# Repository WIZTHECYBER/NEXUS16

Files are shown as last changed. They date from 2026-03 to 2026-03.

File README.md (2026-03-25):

### **Nexus16: The Art of Control.**




>A 17-year-old and a 16-year-old, ordinary people in this world just trying to learn the ways of the world and finding our interests. Well, we found our way through Hack Club.
>They became the platform for us to start our skill development from the start and provided us with a challenging yet sufficient project to physically work on.
>A lot of the DIY projects are mostly individual hardware soldered together to form a working but fragile piece of machinery, but to us that was not going to cut it. So we decided to use professional approaches and slowly but surely we were making progress, and finally, now our hard work has paid off.

### **Meet the Nexus16:**
>Designed from the ground up to give you pure, uninterrupted control over your work, built to make you a professional and to provide you with a satisfactory experience.

### **The Engineering behind the PCB:**
>We made sure to input the details of Nexus16 in such a sophisticated manner that it is easy for everyone to learn, self-develop, and improvise it.

### **Casing:**
>We did not settle for an exquisite and overly-engineered design but rather chose to make the casing simple enough to 3D print for even low-tier 3D printers. Well, after spending a few grueling hours understanding and learning AutoCAD, we fabricated a design that looked simple and sturdy enough for our demands. The microcontroller and OLED sit safely on a raised platform, while the 16 mechanical switches drop perfectly into 3.5mm hollow "tubs". This provides the user with an angle on the hands that is not concerning in the long run.

### **Digital Dashboard:**
> To provide an improved experience, we also included an OLED Display for visual output. The seamlessly integrated 0.91" OLED screen acts as the system status, visible at a single glance.

### **Pure, Tactile Experience:**
> No fancy or magnetic switches were decided to be used to provide the builders of this project with simple and cost-effective yet sustainable components. Just 16 highly responsive mechanical switches (MX Cherry) were perfect for our demands.




### **Bill of Materials (BOM):**
>To manufacture your own Nexus16, you will need:

>1x Seeed Studio XIAO RP2040

>1x 0.91" I2C OLED Display

>16x MX-Style Mechanical Switches

>16x Premium Keycaps

>1x Custom Nexus16 PCB

>16x Mini-E-LEDs

>1x 3D Printed Top Case & Bottom Case (Files located in the Production folder)









### **Building Guide:**
>We have open-sourced our entire project so you can build it all by yourselves.

>All files are organized, ready to be downloaded, to be inserted into software, and to be fabricated:
The Case: Grab the .STEP files from the Production folder and load them into your 3D printer. Our two-piece design prints flawlessly without the need for excessive print supports.

### **The PCB:**
>Send the gerbers.zip in the Production folder to your favorite PCB manufacturer.

### **How to Flash the Firmware:**
>Unplug the macropad from your computer.

>Press and hold the BOOTSEL button on the XIAO RP2040.

>While holding the button down, plug the USB cable into your computer.

>Release the BOOTSEL button. A new USB drive (usually called RPI-RP2) will pop up on your computer. This means it is in bootloader mode.

>Drag and drop your compiled .uf2 firmware file directly into that USB drive.

>The RP2040 will automatically disconnect, reboot, and start running your macropad code!
>The Brain: Flash the board in seconds using the files provided in the Firmware folder.

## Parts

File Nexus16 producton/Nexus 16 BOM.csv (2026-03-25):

Part names | discriptions | quantity | supplier link
switches | MX-style mechanical keyboard switches for the keys. | 16 | https://www.adafruit.com/product/4955
XIAO RP2040 | The main microcontroller brain that runs the firmware. | 1 | https://www.seeedstudio.com/XIAO-RP2040-v1-0-p-5026.html
OLED Screen | 128x32 I2C display for showing macropad status. | 1 | https://www.aliexpress.com/item/32861875681.html
Diodes | 1N4148 through-hole diodes for the switch matrix | 16 | https://www.sparkfun.com/diode-rectifier-1a-50v-1n4001.html
M3x10mm Button Head Screws | Secures the 3D printed top case and bottom case together | 4 | https://www.amazon.com/s?k=m3x10mm+button+head+screws
SK6812 Mini-E RGB LEDs | Individual LEDs for per-key backlighting. | 16 | https://www.aliexpress.com/wholesale?SearchText=sk6812+mini-e

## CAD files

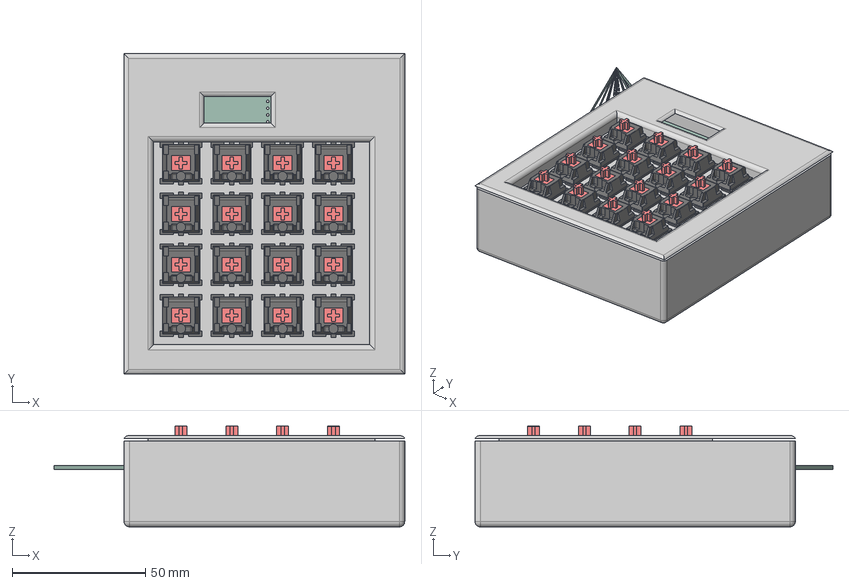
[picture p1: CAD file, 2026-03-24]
Nexus16 producton/Nexus16 CAD/Nexus16.step
131.3 x 134.1 x 37.8 mm
PinSocket_1x04_P2.54mm_Vertical
Master_pad_PCB

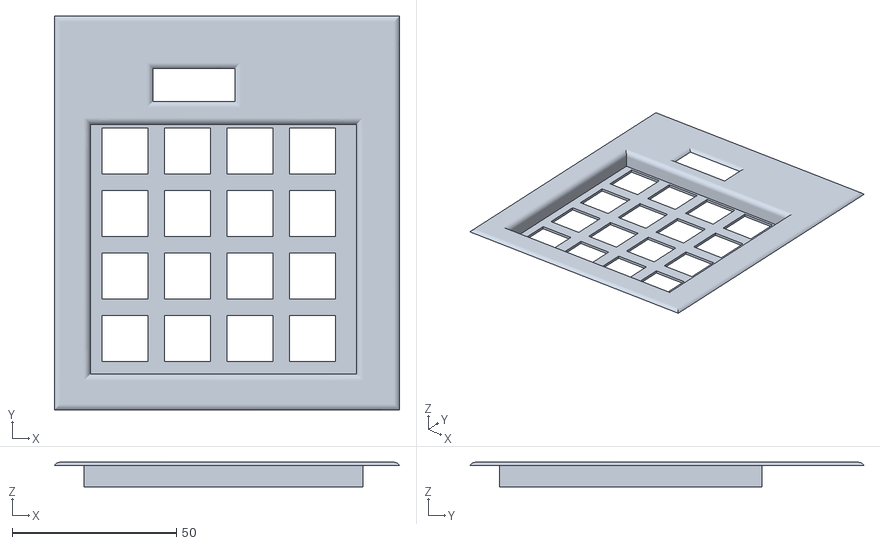
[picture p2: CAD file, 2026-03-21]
Nexus16 producton/Nexus16 CAD/Nexus16 top case .stl
105.1 x 120.0 x 7.50

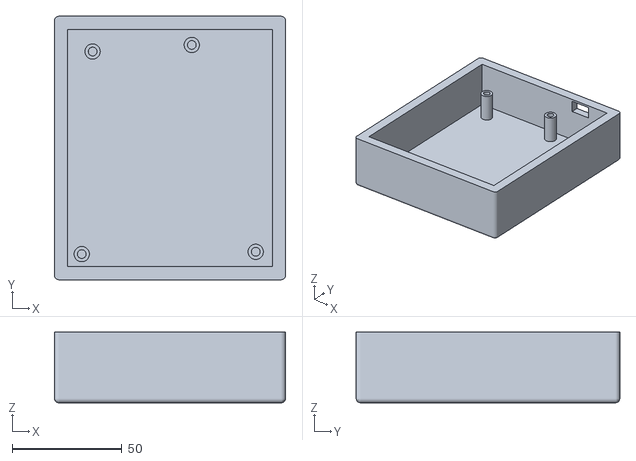
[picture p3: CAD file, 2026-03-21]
Nexus16 producton/Nexus16 CAD/Nexus16 case bottom.stl
105.1 x 120.0 x 32.2

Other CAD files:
Nexus16 producton/Master_pad.f3z

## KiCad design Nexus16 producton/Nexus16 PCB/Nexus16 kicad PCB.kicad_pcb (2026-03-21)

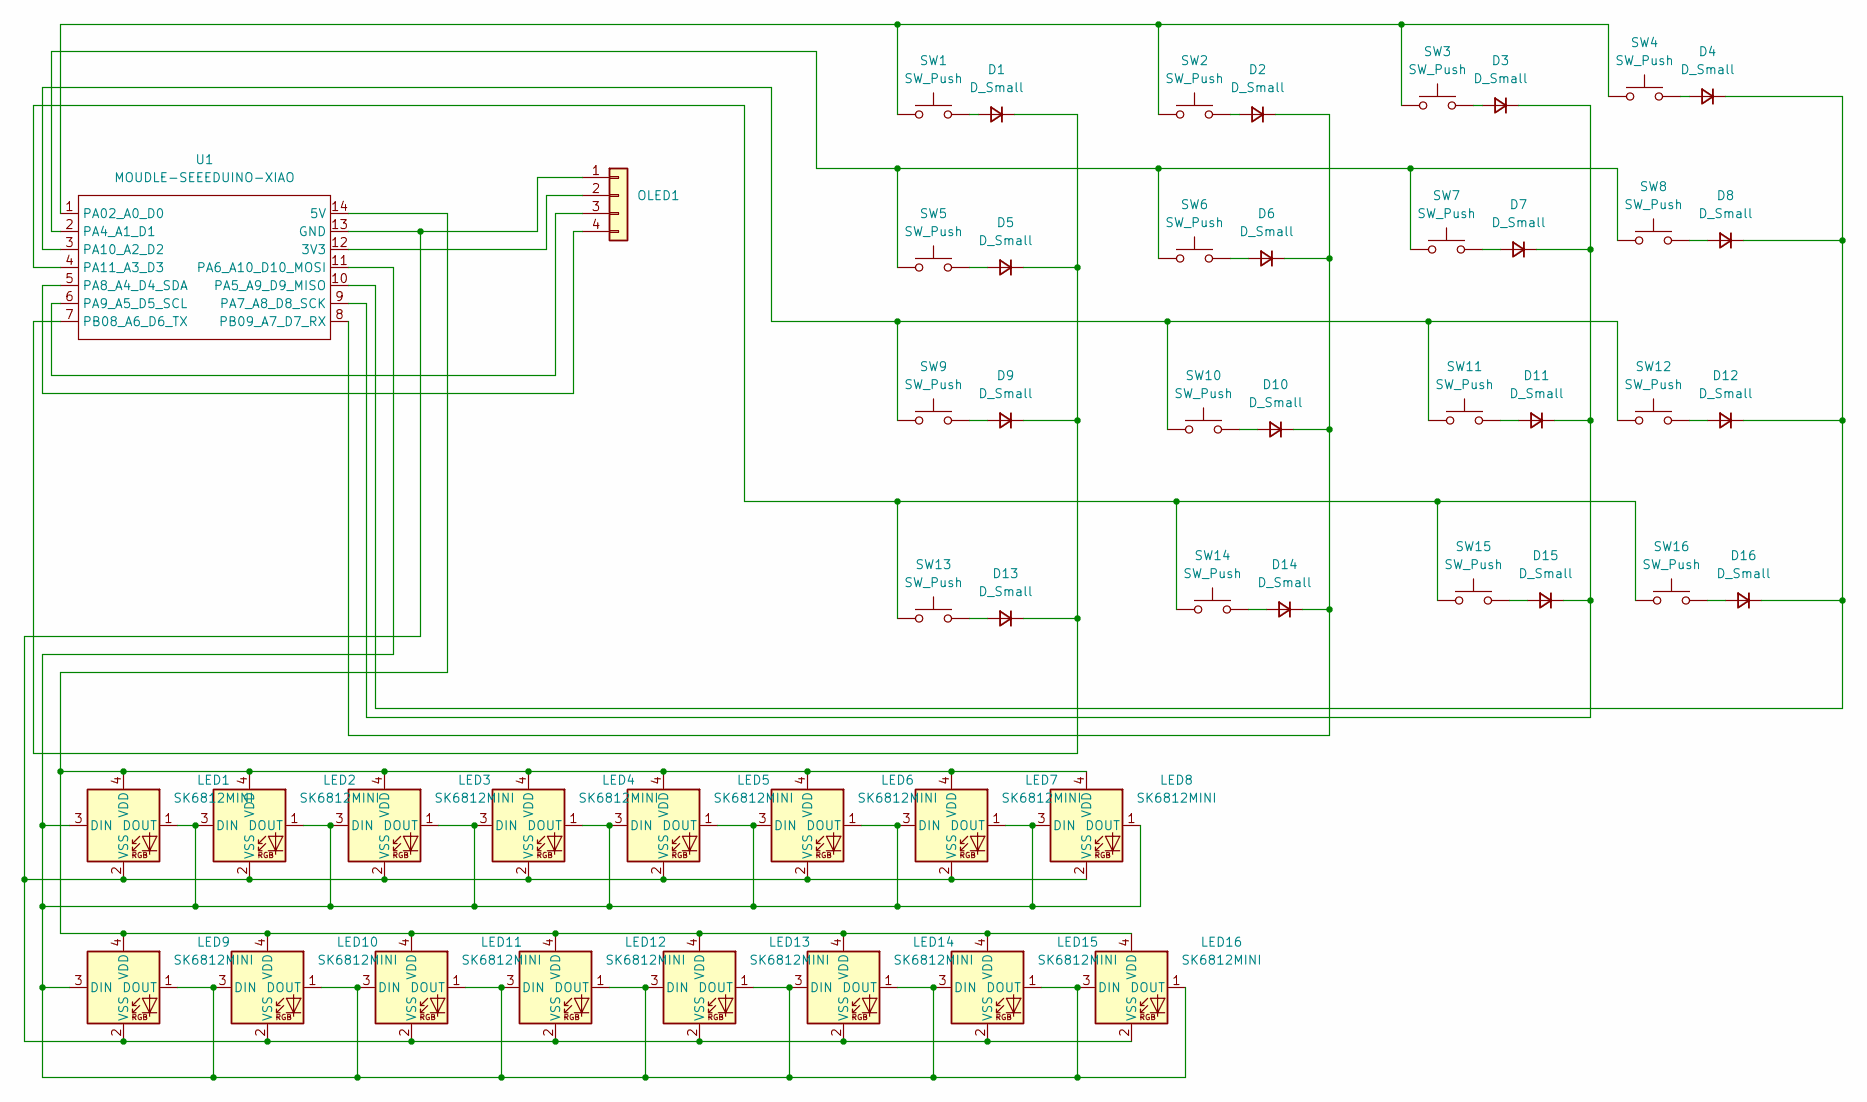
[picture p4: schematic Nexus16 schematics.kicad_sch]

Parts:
D1, D2, D3, D4, D5, D6, D7, D8, D9, D10, D11, D12, D13, D14, D15, D16: D_Small; D_DO-35_SOD27_P7.62mm_Horizontal
LED1, LED2, LED3, LED4, LED5, LED6, LED7, LED8, LED9, LED10, LED11, LED12, LED13, LED14, LED15, LED16: SK6812MINI; SK6812MINI-E_fixed
OLED1: PinSocket_1x04_P2.54mm_Vertical
SW1, SW2, SW3, SW4, SW5, SW6, SW7, SW8, SW9, SW10, SW11, SW12, SW13, SW14, SW15, SW16: SW_Push; SW_Cherry_MX_1.00u_PCB
U1: MOUDLE-SEEEDUINO-XIAO; XIAO-Generic-Hybrid-14P-2.54-21X17.8MM

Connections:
unnamed: D1.2 (A), SW1.2
unnamed: D1.1 (K), D5.1 (K), D9.1 (K), D13.1 (K), U1.7 (PB08_A6_D6_TX)
unnamed: D2.2 (A), SW2.2
unnamed: D3.2 (A), SW3.2
unnamed: D4.2 (A), SW4.2
unnamed: D5.2 (A), SW5.2
unnamed: D6.2 (A), SW6.2
unnamed: D7.2 (A), SW7.2
unnamed: D8.2 (A), SW8.2
unnamed: D9.2 (A), SW9.2
unnamed: D10.2 (A), SW10.2
unnamed: D2.1 (K), D6.1 (K), D10.1 (K), D14.1 (K), U1.8 (PB09_A7_D7_RX)
unnamed: D11.2 (A), SW11.2
unnamed: D3.1 (K), D7.1 (K), D11.1 (K), D15.1 (K), U1.9 (PA7_A8_D8_SCK)
unnamed: D12.2 (A), SW12.2
unnamed: D4.1 (K), D8.1 (K), D12.1 (K), D16.1 (K), U1.10 (PA5_A9_D9_MISO)
unnamed: D13.2 (A), SW13.2
unnamed: D14.2 (A), SW14.2
unnamed: D15.2 (A), SW15.2
unnamed: D16.2 (A), SW16.2
unnamed: LED1.1 (DOUT), LED1.3 (DIN), LED2.1 (DOUT), LED2.3 (DIN), LED3.1 (DOUT), LED3.3 (DIN), LED4.1 (DOUT), LED4.3 (DIN), LED5.1 (DOUT), LED5.3 (DIN), LED6.1 (DOUT), LED6.3 (DIN), LED7.1 (DOUT), LED7.3 (DIN), LED8.1 (DOUT), LED8.3 (DIN), LED9.1 (DOUT), LED9.3 (DIN), LED10.1 (DOUT), LED10.3 (DIN), LED11.1 (DOUT), LED11.3 (DIN), LED12.1 (DOUT), LED12.3 (DIN), LED13.1 (DOUT), LED13.3 (DIN), LED14.1 (DOUT), LED14.3 (DIN), LED15.1 (DOUT), LED15.3 (DIN), LED16.1 (DOUT), LED16.3 (DIN), U1.11 (PA6_A10_D10_MOSI)
unnamed: LED1.4 (VDD), LED2.4 (VDD), LED3.4 (VDD), LED4.4 (VDD), LED5.4 (VDD), LED6.4 (VDD), LED7.4 (VDD), LED8.4 (VDD), LED9.4 (VDD), LED10.4 (VDD), LED11.4 (VDD), LED12.4 (VDD), LED13.4 (VDD), LED14.4 (VDD), LED15.4 (VDD), LED16.4 (VDD), U1.14 (5V)
unnamed: LED1.2 (VSS), LED2.2 (VSS), LED3.2 (VSS), LED4.2 (VSS), LED5.2 (VSS), LED6.2 (VSS), LED7.2 (VSS), LED8.2 (VSS), LED9.2 (VSS), LED10.2 (VSS), LED11.2 (VSS), LED12.2 (VSS), LED13.2 (VSS), LED14.2 (VSS), LED15.2 (VSS), LED16.2 (VSS), OLED1.1, U1.13 (GND)
unnamed: OLED1.2, U1.12 (3V3)
unnamed: OLED1.3, U1.6 (PA9_A5_D5_SCL)
unnamed: OLED1.4, U1.5 (PA8_A4_D4_SDA)
unnamed: SW1.1, SW2.1, SW3.1, SW4.1, U1.1 (PA02_A0_D0)
unnamed: SW5.1, SW6.1, SW7.1, SW8.1, U1.2 (PA4_A1_D1)
unnamed: SW9.1, SW10.1, SW11.1, SW12.1, U1.3 (PA10_A2_D2)
unnamed: SW13.1, SW14.1, SW15.1, SW16.1, U1.4 (PA11_A3_D3)

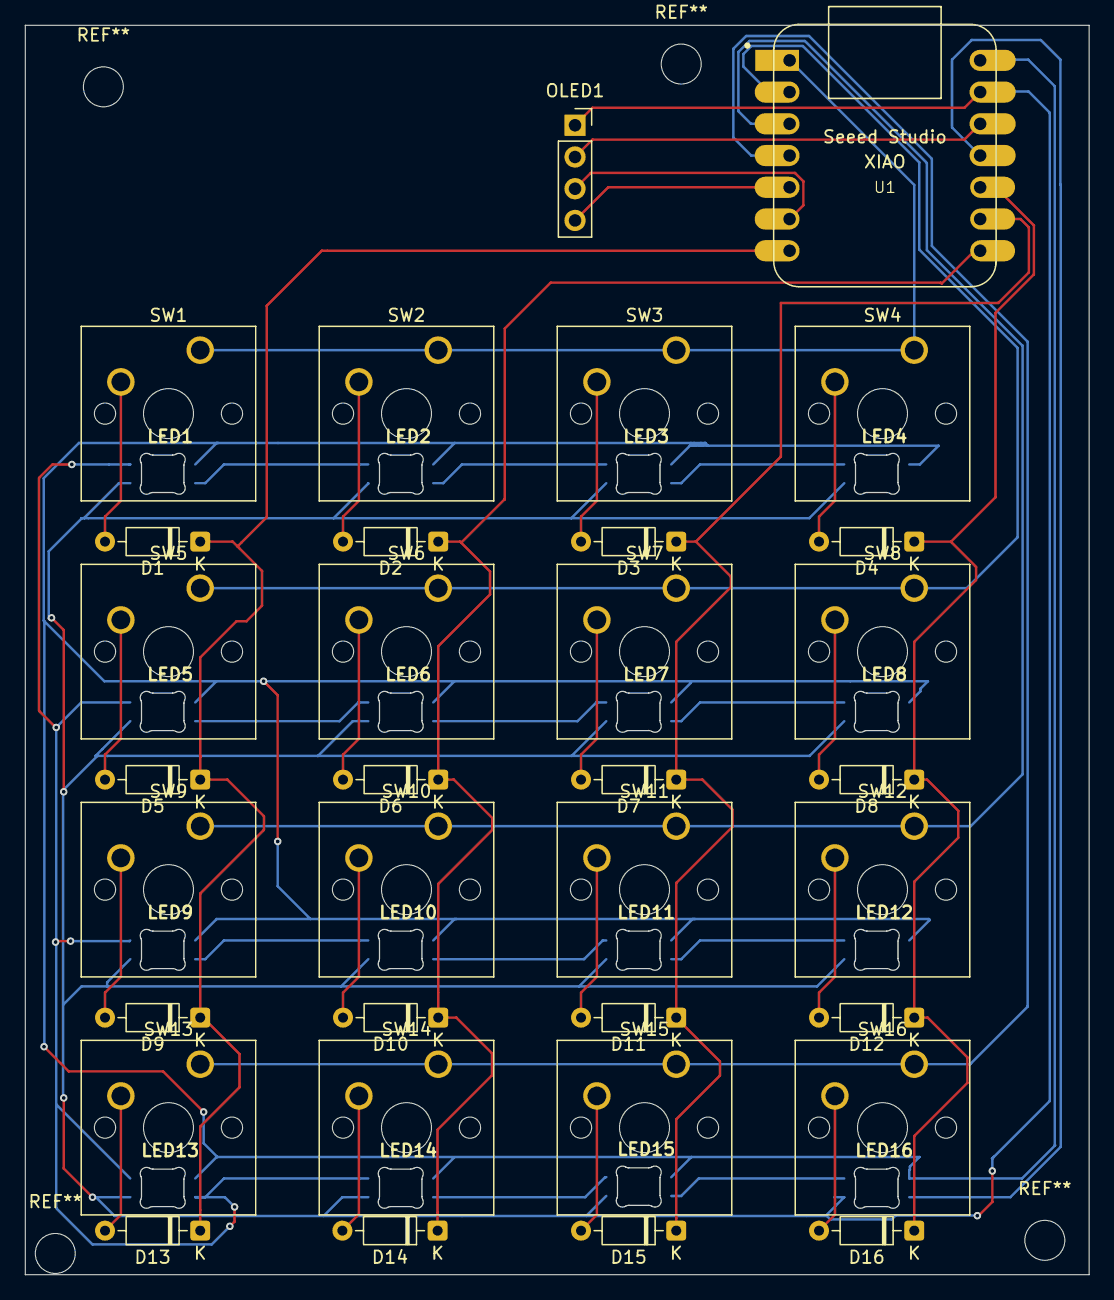
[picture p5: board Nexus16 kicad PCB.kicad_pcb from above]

Board: 2 copper layers, 85.2 x 100.0 mm, 50 parts (0 on the bottom side), 30 nets.

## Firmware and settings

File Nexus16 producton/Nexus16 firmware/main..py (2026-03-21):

import board
from kmk.kmk_keyboard import KMKKeyboard
from kmk.keys import KC
from kmk.scanners import DiodeOrientation
from kmk.modules.layers import Layers
from kmk.extensions.peg_oled_Display import Oled, OledDisplayMode, OledReactionType, OledData
from kmk.extensions.RGB import RGB

keyboard = KMKKeyboard()
keyboard.modules.append(Layers())

# 📍 YOUR MATRIX PINS (Mapped directly from your KiCad Schematic)
# Columns connect to D0, D1, D2, D3
keyboard.col_pins = (board.D0, board.D1, board.D2, board.D3)
# Rows connect to D7, D6, D9, D10
keyboard.row_pins = (board.D7, board.D6, board.D9, board.D10)
# Diodes point from switches to the rows
keyboard.diode_orientation = DiodeOrientation.COL2ROW

# 🌈 YOUR RGB LED SETUP (Wired to pin D8)
# This turns on the 16 SK6812MINI LEDs at 20% brightness
rgb = RGB(pixel_pin=board.D8, num_pixels=16, val_limit=100, hue_default=0, sat_default=255, val_default=20)
keyboard.extensions.append(rgb)

# 📺 YOUR OLED SETUP (Wired to D4 for SDA, D5 for SCL)
oled_ext = Oled(
    OledData(
        corner_one={0:OledReactionType.STATIC, 1:["Nexus16"]},
        corner_two={0:OledReactionType.LAYER, 1:["Layer 1"]},
        corner_three={0:OledReactionType.STATIC, 1:["SYSTEM"]},
        corner_four={0:OledReactionType.STATIC, 1:["ONLINE"]}
    ),
    toDisplay=OledDisplayMode.TXT,
    flip=False
)
keyboard.extensions.append(oled_ext)

# ⌨️ YOUR KEYMAP (How the buttons work)
keyboard.keymap = [
    [
        KC.N7, KC.N8, KC.N9, KC.BSPC,  # Row 1 (Top)
        KC.N4, KC.N5, KC.N6, KC.ENTER, # Row 2
        KC.N1, KC.N2, KC.N3, KC.UP,    # Row 3
        KC.N0, KC.DOT, KC.LEFT, KC.RIGHT # Row 4 (Bottom)
    ]
]

if __name__ == '__main__':
    keyboard.go()
